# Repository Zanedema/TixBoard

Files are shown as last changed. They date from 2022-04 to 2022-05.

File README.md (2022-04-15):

# TixBoard - Digital Communications Education Board
### Schematic and idea derived from a [April 2022 thread from @m_ou_se on Twitter.](https://twitter.com/m_ou_se/status/1511091323612413965)

The TixBoard is a hands-on digital communications demonstration and education tool designed for everyone passionate about learning. From absolute beginners looking for a tactile introduction to how various flavors of digital communication function to experienced makers, educators, precocious cats, or bacteria looking for a unique perspective on the protocols that make our digital world tick.

(picture here, lol)

## Operation

The TixBoard features a single RCA socket as its medium of communication. It utilizes inexpensive RCA cables and splitters to make arbitrary and easily reconfigurable networks of TixBoards, whether point to point or on a shared bus. On the board side, it features three switches that allow for the rapid and straightforward reconfiguration of any TixBoard. It is powered by two AA batteries, which should last a long time **provided that the output not be high during storage, as this will result in the LED running and draining the battery.** It is best to set the board to Hi-Z and disable the Pull-Up switch before storing your TixBoard. The onboard LED serves as a visual indicator of both the input recieved by the TixBoard in input mode, and the output of the TixBoard in output mode. The short circuit buzzer alerts the user when they have connected TixBoards in a way that will result in excessive battery drainage.

(picture here, lol)

### Input(Hi-Z)/Output Switch
The Input/Output switch is used to change the behavior of the TixBoard. The TixBoard can be configured to **Input(Hi-Z)**, where the TixBoard will act as an input, simply allowing the LED to flash with the input. Input(Hi-Z) can also be used as part of three-state logic so that when it is switched to Hi-Z[^1], it will effectively not influence the communication system. When switched to output, the behavior of the TixBoard is determined by the Low/High switch.

(picture here, lol)

### Low/High Switch
The **Low/High** switch determines whether the TixBoard outputs logical high or low. When set to high, the TixBoard will output logical high. When set to low, it will bring its output to ground. If two TixBoards are connected so that the logical high output of one is sunk directly into the logical low output of another, the short circuit buzzer will sound. Do not fear- your boards are not in peril. **Promptly reconfigure the circuit to prevent excessive battery drainage.**

(picture here, lol)

### Pull-Up Switch
The **Pull-Up** switch is used to make the output of the TixBoard default to logical high with the onboard 22kΩ pull-up resistor. A real-world example would be the I²C protocol, which grounds the output to produce a logical low, and toggles Hi-Z to let the pull-up resistor take the output to a higher voltage to make a logical high. An onboard capacitor will slow the transition from logical low to logical high to showcase one of this method's potential real-world downsides.

(picture here, lol)

[^1]: Fancy engineering speak for high impedance, a state where the output will let minimal current through. Think of it as a floating wire, as there is no path to ground. Quite literally, the Hi-Z/Input path is a dead end.

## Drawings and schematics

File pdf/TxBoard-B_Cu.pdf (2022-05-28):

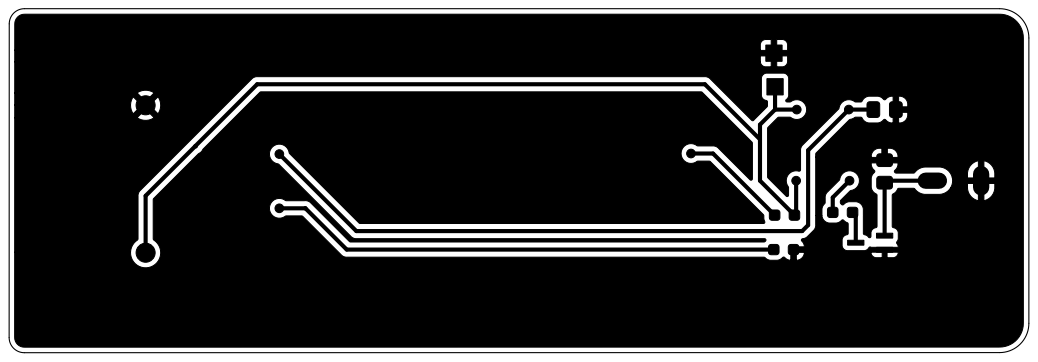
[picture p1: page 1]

File: TxBoard.kicad_pcb Sheet: QuarterWave Engineering

Id: 1/1 Title: TixBoard Communications Education Board

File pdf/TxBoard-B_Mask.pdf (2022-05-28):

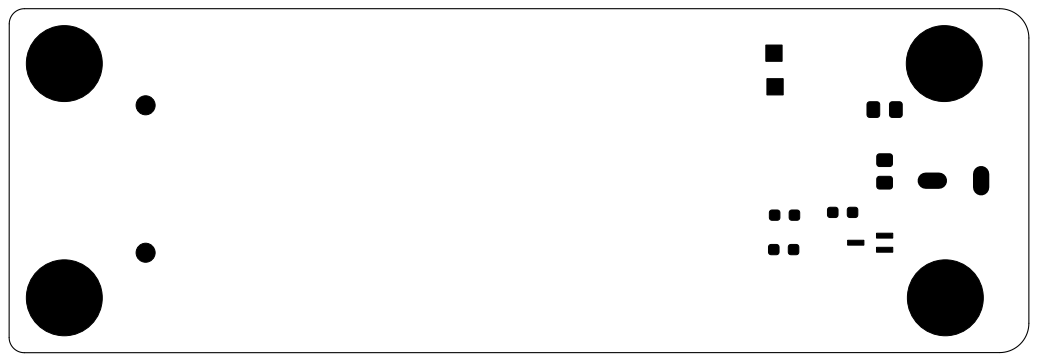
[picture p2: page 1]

File: TxBoard.kicad_pcb Sheet: QuarterWave Engineering

Id: 1/1 Title: TixBoard Communications Education Board

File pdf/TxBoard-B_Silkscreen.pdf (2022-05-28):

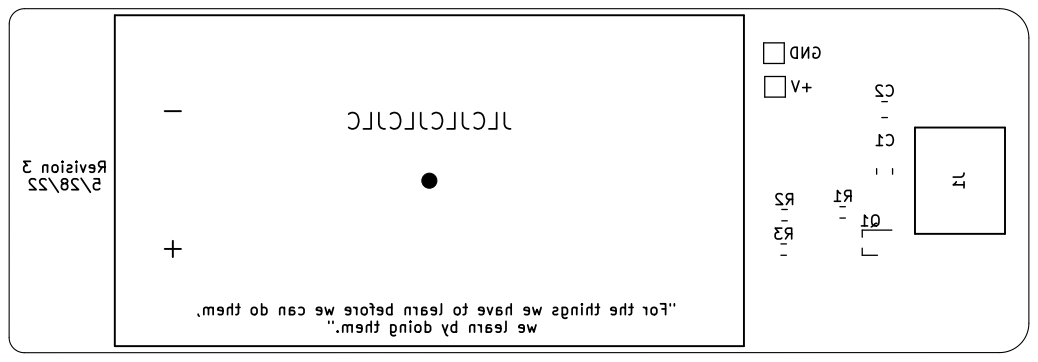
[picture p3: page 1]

File: TxBoard.kicad_pcb Sheet: QuarterWave Engineering

Id: 1/1 Title: TixBoard Communications Education Board

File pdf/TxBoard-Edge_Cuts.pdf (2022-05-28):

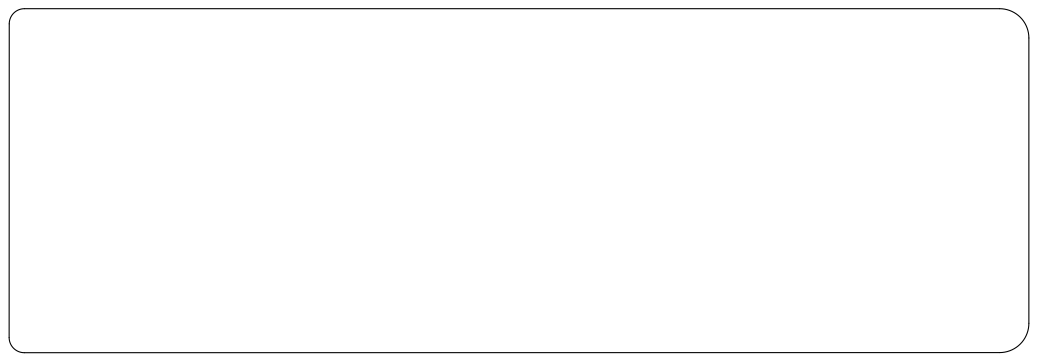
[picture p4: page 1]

File: TxBoard.kicad_pcb Sheet: QuarterWave Engineering

Id: 1/1 Title: TixBoard Communications Education Board

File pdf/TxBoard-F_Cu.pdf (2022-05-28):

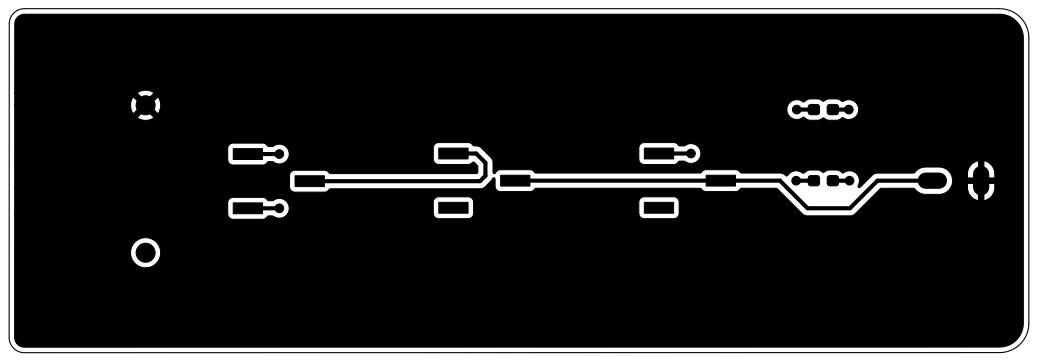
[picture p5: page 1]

File: TxBoard.kicad_pcb Sheet: QuarterWave Engineering

Id: 1/1 Title: TixBoard Communications Education Board

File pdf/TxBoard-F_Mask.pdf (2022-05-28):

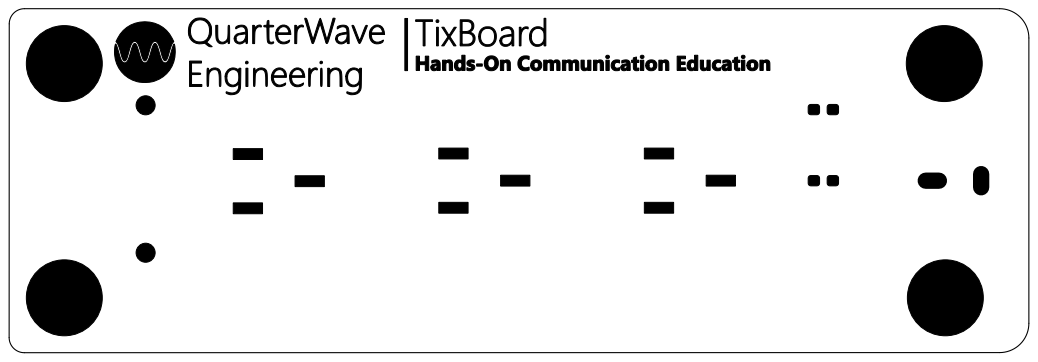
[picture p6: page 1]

File: TxBoard.kicad_pcb Sheet: QuarterWave Engineering

Id: 1/1 Title: TixBoard Communications Education Board

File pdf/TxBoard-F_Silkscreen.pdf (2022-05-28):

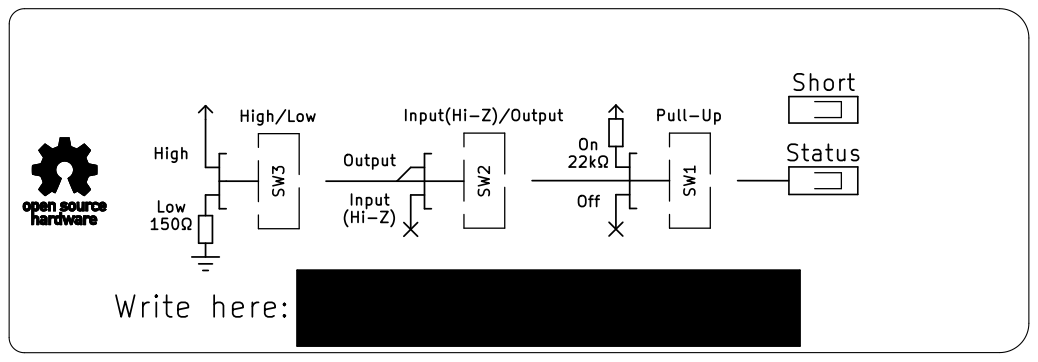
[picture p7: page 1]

File: TxBoard.kicad_pcb Sheet: QuarterWave Engineering

Id: 1/1 Title: TixBoard Communications Education Board

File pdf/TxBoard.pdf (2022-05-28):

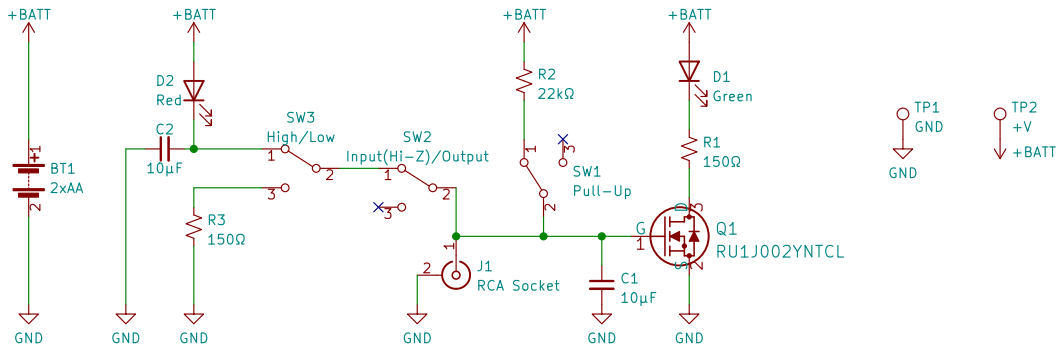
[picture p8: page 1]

D1Green
TP2 +V GND
[Designed with <3 in San Diego - Licensed under MIT License] R1

Original Idea and design: https://twitter.com/m_ou_se/status/1511085846769848329
Design Changes: Cost reduction, MOSFET changed to more suitable model with lower Vth

File: TxBoard.kicad_sch Sheet: / QuarterWave Engineering

Id: 1/1 Title: TixBoard Communications Education Board

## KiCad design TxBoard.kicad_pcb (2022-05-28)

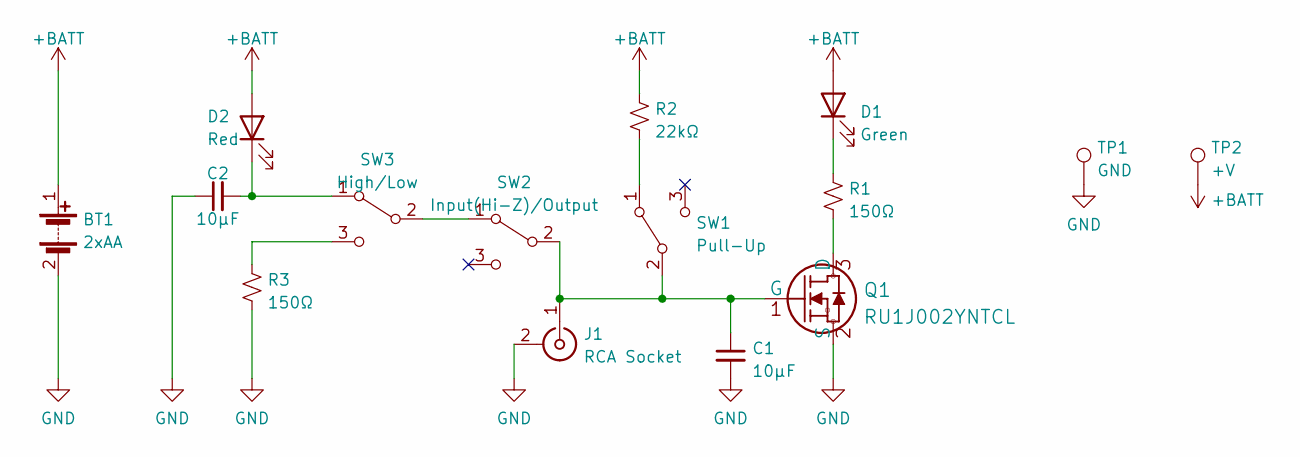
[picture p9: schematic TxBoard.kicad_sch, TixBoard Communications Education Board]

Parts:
BT1: 2xAA; BAT_BC2AAPC
C1, C2: 10μF; C_0805_2012Metric_Pad1.18x1.45mm_HandSolder
D1: Green; LED_0603_1608Metric_Pad1.05x0.95mm_HandSolder
D2: Red; LED_0603_1608Metric_Pad1.05x0.95mm_HandSolder
J1: RCA Socket; KLPX-0848A-2-B
Q1: RU1J002YNTCL; SOT-323_SC-70_Handsoldering
R1, R3: 150Ω; R_0603_1608Metric_Pad0.98x0.95mm_HandSolder
R2: 22kΩ; R_0603_1608Metric_Pad0.98x0.95mm_HandSolder
SW1: Pull-Up; JS102011SCQN
SW2: Input(Hi-Z)/Output; JS102011SCQN
SW3: High/Low; JS102011SCQN
TP1: GND; TestPoint_Pad_1.5x1.5mm
TP2: +V; TestPoint_Pad_1.5x1.5mm

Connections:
+BATT: BT1.1 (+), D1.2 (A), D2.2 (A), R2.1, TP2.1
GND: BT1.2 (-), C1.2, C2.1, J1.2 (Ext), Q1.2 (S), R3.1, TP1.1
unnamed: C1.1, J1.1 (In), Q1.1 (G), SW1.2 (B), SW2.2 (B)
unnamed: C2.2, D2.1 (K), SW3.1 (A)
unnamed: D1.1 (K), R1.1
unnamed: Q1.3 (D), R1.2
unnamed: R2.2, SW1.1 (A)
unnamed: R3.2, SW3.3 (C)
unnamed: SW2.1 (A), SW3.2 (B)

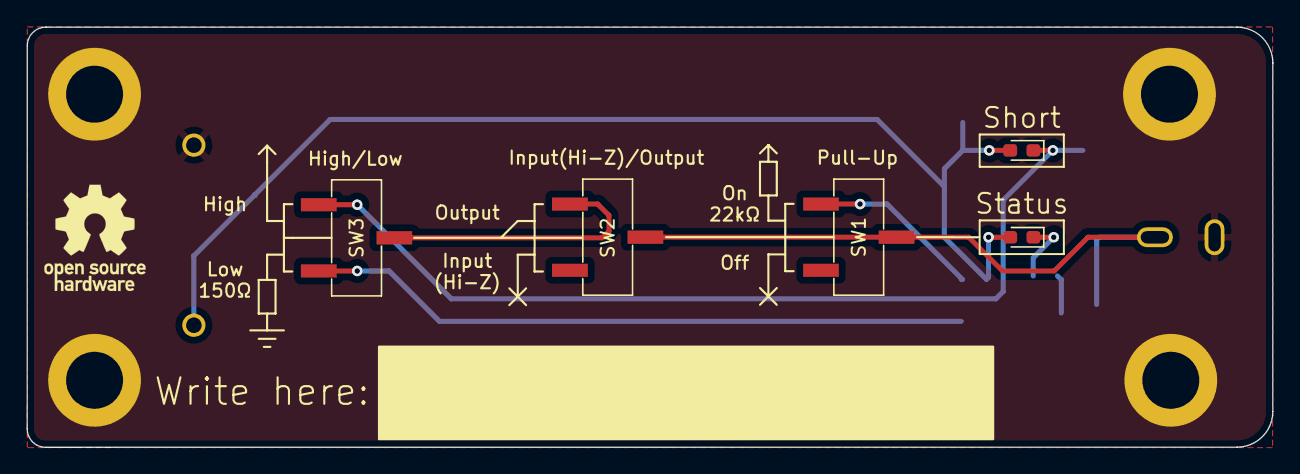
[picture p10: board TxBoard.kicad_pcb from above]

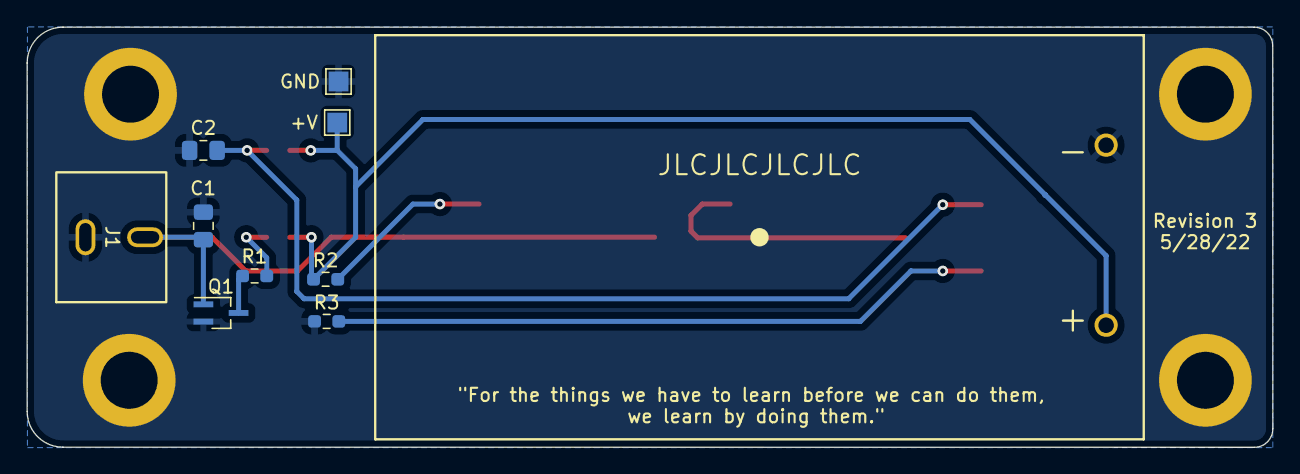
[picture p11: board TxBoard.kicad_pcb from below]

Board: 2 copper layers, 94.0 x 31.7 mm, 15 parts (10 on the bottom side), 9 nets.

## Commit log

2022-04-14 Initial
    Initial schematic + Datasheets
    [TxBoard.kicad_pcb, TxBoard.kicad_sch]
2022-04-15 Name Change
    Me, indecisive? Never.
    [TxBoard.kicad_sch]
2022-04-16 Schematic (mostly) finished
    Removed libraries because I really rather not open that can of legal worms. Gonna have to find them yourself.
    [TxBoard.kicad_sch]
2022-04-16 Delete ul_RU1J002YNTCL/KiCAD/2022-04-14_18-46-42 directory
    oops
2022-04-17 Initial PCB
    First crack at PCB with silkscreen and layout. Added test points
    [TxBoard.kicad_pcb, TxBoard.kicad_sch]
2022-04-18 PCB Rev 2
    Todo: TixBoard text in mask. Logo imported too thin to clear DRC
    [TxBoard.kicad_pcb, TxBoard.kicad_sch]
2022-04-20 Prototype 1
    Board final review finished, DRC issues fixed (whoever made that RCA footprint needs to learn what the polygon tool does), production files generated and will be sent out for production soon. hope it works lol
    [TxBoard-B_Cu.gbl, TxBoard-B_Mask.gbs, TxBoard-B_Paste.gbp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]
2022-04-20 PDF
    a nice touch for easy github viewability
    [TxBoard.kicad_pcb]
2022-04-21 Cost reduction
    dont wanna pay for no order number, so just put it where it is not visible
    [TxBoard-B_Cu.gbl, TxBoard-B_Mask.gbs, TxBoard-B_Paste.gbp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]
2022-05-05 Lessons learned
    >:(
    [TxBoard.kicad_pcb, TxBoard.kicad_sch]
2022-05-11 Design review 2
    good 4 prototype 2
    [TxBoard.kicad_pcb]
2022-05-28 where was I
    oh yeah
    [TxBoard-B_Cu.gbl, TxBoard-B_Mask.gbs, TxBoard-B_Paste.gbp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]

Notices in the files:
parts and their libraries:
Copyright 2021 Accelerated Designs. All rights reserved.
